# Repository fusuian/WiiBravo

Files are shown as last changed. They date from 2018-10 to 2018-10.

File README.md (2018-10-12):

# WiiBravoアダプタ

ソニー製PlayStation1/2用ゲームコントローラを任天堂製ゲームコントローラWiiリモコンに接続するアダプタです。

DualShock2をクラシックコントローラの代わりとして使えるほか、ナムコ（現バンダイナムコゲームス）製バーチャルコンソールアーケードソフト『超絶倫人ベラボーマン』用に、ボタンを押す強さによって弱中強攻撃（ジャンプ）を行う機能があります。

また、PS用のアーケードコントローラを接続することもできます。
このとき、バーチャルコンソールのファミコンソフトとメガドライブソフトが遊びやすいようにボタン配列を変更できます。

## ハードウェア

WiiBravoアダプタは、マイコンボードと電子部品をブレッドボードに組み付けて作成します。

ブレッドボードの配線図は、 WiiBravo.fzz またはWiiBravo_BreadBoard.pdfをご覧ください。

 - ブレッドボード ハーフサイズ
 - マイコンボード Arduino Pro mini (3.3V版)
 - カーボン抵抗 560Ω x 1
 - カーボン抵抗 1kΩ x 3
 - 赤、黄、青色のLED 各1
 - ジャンパワイヤ 適宜

 - PlayStationコネクタ (マルチタップなどを分解して入手) x 1
 - Wiiリモコンケーブル (ヌンチャクのケーブルを切断) x 1

## ソフトウェア

USBシリアル変換モジュールでPCとArduino Pro Miniを接続して、
Arduino IDEで WiiBravo スケッチを書き込みます。

 - WiiBravo.ino         スケッチ本体
 - BravoButton.h        ベラボースイッチクラス
 - portmacro.h          digitalWrite に相当する、portOn/portOffマクロを定義

以下のソフトウェアは、Bruno Freitas氏によるwii-retropad-adapterをもとに、Arduino 1.8でビルドするための変更を加えています。

https://github.com/bootsector/wii-retropad-adapter

 - WMExtension.h/cpp    Wiiリモコン拡張コントローラ通信クラス
 - WMCrypt.h/cpp        Wiiリモコン拡張コントローラ通信暗号化クラス

### PS2X_libライブラリ

Bill Porter氏による、PlayStationコントローラ読み取りライブラリです。

https://github.com/madsci1016/Arduino-PS2X からダウンロードして、Arduino/libraliesフォルダに展開してください。

### ライセンス

ソフトウェアのライセンスはGPL3となります。詳しくはWiiBravo.inoをご覧ください。

## 使用方法

WiiBravoアダプタに PlayStationコントローラを接続してから、Wiiリモコンを接続します。

DualShock2とアーケードコントローラをつなぎ換える場合は、一度WiiBravoアダプタを外してからコントローラを抜き差ししてください。

### クラシックコントローラモード

PlayStationコントローラとしてDualShock2を接続すると、赤のLEDが1秒間点滅して、クラシックコントローラモードで起動します。

クラシックコントローラモードでは、ボタンは以下のように対応します。

                  DualShock2  : Wii クラシックコントローラ
                  R1 □ △ L1 :  R y x L
                  R2 ✕ ◯ L2 : ZR b a ZL

### ベラボーマンモード

クラシックコントローラモードで、SELECTボタンとL1ボタンを一緒に押すと青のLEDが1秒間点滅して、ベラボーマンモードになります。

ベラボーマンモードでは、△ボタンと✕ボタンが攻撃ボタンになり、□ボタンと◯ボタンがジャンプボタンになります。

各ボタンは、押し込む強さによって三段階の強さの攻撃またはジャンプになります。

(攻撃ボタンはy,x,L、ジャンプボタンはb,a,Rのいずれかを押したことになる)

L1ボタンとR1ボタンは使用しません。

R2ボタンでコイン投入、L2ボタンまたはSTARTボタンでゲームスタートとなります。

ベラボーマンモードでSELECTボタンとR1ボタンを一緒に押すと、クラシックコントローラモードになります。

### アーケードコントローラモード

PlayStationコントローラとしてアーケードコントローラを接続すると、赤のLEDが約1秒間点滅してアーケードコントローラモードで起動します。

作者はHORI製リアルアーケードPSのボタン配置を改造したものを使用していますが、他社製のコントローラでも使えると思います。

アーケードコントローラモードでは、ボタンは以下のように対応します。

       アーケードコントローラ : Wiiクラシックコントローラ
                  L2 □ △ L1 : ZL y x L
                  R2 ✕ ◯ R1 : ZR b a R

### ファミコンモード

また、SELECTボタンとL1ボタンを同時に押すと、黄色のLEDが約1秒間点滅してファミコンモードに移行します。

ファミコンモードでは、ボタンは以下のように対応します。

       アーケードコントローラ : Wiiクラシックコントローラ
                  L2 □ △ L1 : ZL y b a
                  R2 ✕ ◯ R1 : ZR x y a

このとき、上の段の y,b,a は、バーチャルコンソールのメガドライブソフトでは、メガドライブコントローラのA,B,Cボタンとして機能します。

そして下の段の x,y,a は、バーチャルコンソールのファミコンソフトでは、A,B,Aボタンとして機能します。

ファミコンモードでSELECTボタンとR1ボタンを同時に押すと、黄色のボタンが約1秒間点滅してアーケードコントローラモードに戻ります。

# トラブルシューティング

## PlayStationコントローラをつないでも方向キーやボタンが使えない

赤のLEDが長い周期で点滅していた場合、PlayStationコントローラを認識できていません。

このときは、WiiBravoアダプタからPlayStationコントローラを外し、WiiリモコンからWiiBravoアダプタを外し、もう一度接続し直してください。

それでも解決しない場合は、PlayStationコントローラまわりの配線やWiiケーブルを確認してください。

## ホームキーを押すには

Wiiコントローラのホームキーを押すには、SELECTボタンと方向キーの上を同時に押します。

## ベラボーマンモードで、弱中強の押し分けがうまくいかない

ソースコードWiiBravo.inoを修正して、Arduino Pro Miniのプログラムを更新します。

    const byte      low_max =  128;
    const uint16_t  middle_max   =  1000;

low_maxは、0～255までの値をとりますが、値が大きすぎると中や強が出にくくなります。
middle_maxは0～65535までの値をとりますが、low_maxより小さくしてはいけません。また、low_maxに近い値では中が出にくく、値が大きすぎると強が出にくくなります。

ボタンを押したフレームにおける押し下げ圧p1がlow_maxより小さければ弱、次のフレームでの押し下げ圧をp2として、p1*p2がmiddle_maxより小さいとき中、大きいとき強として判定します。

## アーケードコントローラモードで、ボタン配列を変更したい

ソースコードWiiBravo.ino内のac_buttons関数を修正して、Arduino Pro Miniのプログラムを更新します。

    void ac_buttons()
    {
      ab = ps2x.Button(PSB_CIRCLE);
      bb = ps2x.Button(PSB_CROSS);
      xb = ps2x.Button(PSB_TRIANGLE);
      yb = ps2x.Button(PSB_SQUARE);
      lb = ps2x.Button(PSB_L1);
      rb = ps2x.Button(PSB_R1);

      lt = lb*255;
      rt = rb*255;
    }

上記のプログラムでは、左辺であるab, bb, xb, yb, lb, rbはそれぞれWiiクラシックコントローラのa,b,x,y,L,Rボタンに対応します。

右辺のps2x.Buttonのカッコ内のPSB_CIRCLE, PSB_CROSS, PSB_TRIANGLE, PSB_SQUARE, PSB_L1, PSB_R1は、それぞれPlayStationアーケードコントローラの◯,✕,△,□,L1,R1ボタンに対応します。

手持ちのコントローラに合わせてそれぞれの代入式を変更してください。

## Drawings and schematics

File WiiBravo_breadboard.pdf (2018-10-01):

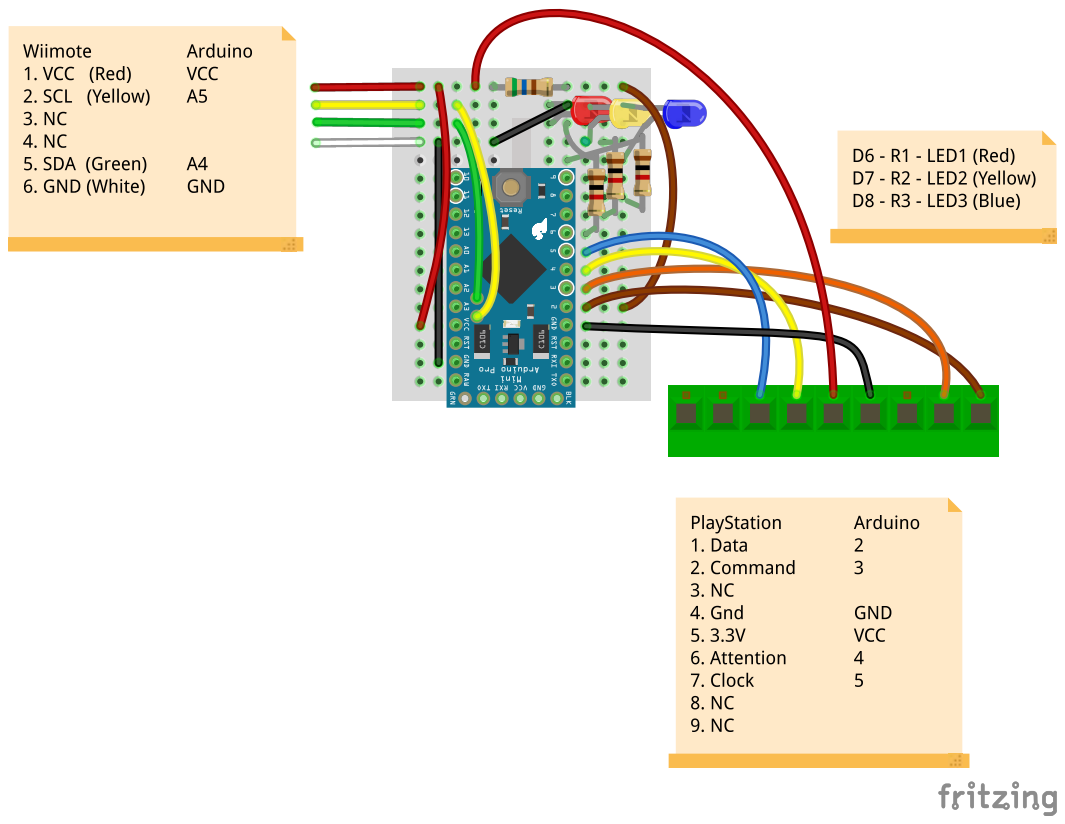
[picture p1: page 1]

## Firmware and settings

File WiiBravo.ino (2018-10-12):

/**
 * WiiBravo - Sony DualShock2 Controller Adapter for Wii (especially designed for Bravoman)
 * Copyright (c) 2018 ASAHI,Michiharu <fusuian@gmail.com>
 *
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
 * You should have received a copy of the GNU General Public License
 * along with WiiBravo.  If not, see <http://www.gnu.org/licenses/>.
 */


#include <PS2X_lib.h>  // v1.6
#include "WMExtension.h"
#include "BravoButton.h"
#include "portmacro.h"

#define ULONG_MAX (4294967295)

// ベラボーマンモードでの、弱中強のしきい値
const byte      low_max =  128;
const uint16_t  middle_max   =  1000;

// DualShock2のアナログスティックのしきい値
const byte threshold = 64;

// 動作モードフラグ

// DualShock2モード
// true: DualShock2が接続されている
// false: PS1初代コントローラまたはアーケードコントローラが接続されている
bool ds2_mode = false;

// ベラボーモード
// select+Rでオン、select+Lでオフ
// ds2_mode が真:
//      true: DualShock2のボタンがそれぞれ、弱中強３段階の攻撃/ジャンプボタンになる。
//      false: クラシックコントローラ配列
// ds2_mode が偽:
//      true: PS1コントローラのボタンをVCのメガドライブ配列(上段)
//            ファミコン配列(下段)に割り当てる
//      false: クラシックコントローラ配列
bool bravo_mode = false;


BravoButton attack_button(low_max, middle_max);
BravoButton jump_button(low_max, middle_max);
BravoButton attack_button2(low_max, middle_max);
BravoButton jump_button2(low_max, middle_max);

// インジケータLEDピン
const byte weak_pin = 6;
const byte middle_pin = 7;
const byte strong_pin = 8;
const byte red_pin = 6;



// PlayStation コントローラ読み取りピン
#define PS2_DAT       2
#define PS2_CMD       3
#define PS2_SEL       4
#define PS2_CLK       5

#define pressures   true
#define rumble      false

PS2X ps2x;

int error = 0;
byte type = 0;
byte vibrate = 0;

// Wiiリモコンへ送る各ボタンのフラグ
byte up, down, left, right;
byte start, select, home;
byte ab, bb, xb, yb;   // A/B/X/Yボタン
byte lb, rb, zlb, zrb; // L/R/ZL/ZRボタン
byte lx, ly, rx, ry;   // アナログスティックL/R
byte lt, rt;           // アナログトリガーL/R

byte clx, cly, crx, cry;  // アナログスティックの中央値

// エラーが発生したら赤LEDをチカチカさせる
void stop_by_error()
{
  while (true) {
    digitalWrite(red_pin, HIGH);
    delay(100);
    digitalWrite(red_pin, LOW);
    delay(900);
  }
}


void setup()
{
  Serial.begin(57600);
  while (Serial == false)
    ;

  pinMode(weak_pin, OUTPUT);
  pinMode(middle_pin, OUTPUT);
  pinMode(strong_pin, OUTPUT);
  portOff(weak_pin);
  portOff(middle_pin);
  portOff(strong_pin);

  // PSコントローラ初期化
  error = ps2x.config_gamepad(PS2_CLK, PS2_CMD, PS2_SEL, PS2_DAT, pressures, rumble);
  Serial.print(F("error = "));
  Serial.println(error);
  if (error == 0){
    Serial.println(F("Found Controller, configured successful"));
  } else if (error == 1) {
    Serial.println(F("No controller found"));
    stop_by_error();
  } else if (error == 2) {
    Serial.println(F("Controller found but not accepting commands"));
  } else if (error == 3) {
    Serial.println(F("Controller refusing to enter Pressures mode"));
  }

  // DualShock2であればベラボーマンモード、PS1コントローラであればデジタルモード
  type = ps2x.readType();
  Serial.print(F("type = "));
  Serial.println(type);
  switch(type) {
  case 0:
    Serial.println(F("Digital Controller found"));
    break;
  case 1:
    Serial.println(F("DualShock Controller found"));
    ds2_mode = true;
    break;
  default:
    Serial.println(F("Unknown Controller found"));
    stop_by_error();
    break;
  }

  if (ds2_mode) {
    while (ps2x.enablePressures() == false) {
      delay(16);
    }
  }
  blinkStart(pinx(), 60);

  // Wiiリモコン初期化
  WMExtension::init();
  Serial.println(F("WM init"));
  clx = WMExtension::get_calibration_byte(2);
  cly = WMExtension::get_calibration_byte(5);
  crx = WMExtension::get_calibration_byte(8);
  cry = WMExtension::get_calibration_byte(11);
}

// 1/60秒単位のウェイトをより正確に
void delay16()
{
  static unsigned long m = 0;
  unsigned long n = micros();

  if (n >= m) {
    n -= m;
  } else {
    n += ULONG_MAX - m;
  }
  delayMicroseconds(10000 - n);
  delayMicroseconds(6666);
  m = micros();
}

byte blink_count;
byte blink_pin;
byte blink_mode;
const byte blink_frames = 5;


void bravo_buttons()
{
  lt = rt = 0;
  yb = xb = lb = 0;
  bb = ab = rb = 0;
  byte vsquare = ps2x.Analog(PSAB_SQUARE);
  jump_button2.update(vsquare, bb, ab, rb);
  byte vcircle = ps2x.Analog(PSAB_CIRCLE);
  jump_button.update(vcircle, bb, ab, rb);
  byte vcross = ps2x.Analog(PSAB_CROSS);
  attack_button.update(vcross, yb, xb, lb);
  byte vtriangle = ps2x.Analog(PSAB_TRIANGLE);
  attack_button2.update(vtriangle, yb, xb, lb);
}


void digital_keys()
{
  lx = left? 0 : (right? 255 : clx);
  ly = down? 0: (up? 255: cly);
  rx = left? 0 : (right? 255 : crx);
  ry = down? 0: (up? 255: cry);
}


void analog_sticks()
{
  // クラコンのアナログスティックのビット幅の変換はライブラリに任せる
  lx =  ps2x.Analog(PSS_LX);
  if (abs(lx) < threshold) { lx = 0; }
  ly =  255 - ps2x.Analog(PSS_LY); // y軸を反転
  if (abs(ly) < threshold) { ly = 0; }

  rx =  ps2x.Analog(PSS_RX);
  if (abs(rx) < threshold) { rx = 0; }
  ry = 255 - ps2x.Analog(PSS_RY); // y軸を反転
  if (abs(ry) < threshold) { ry = 0; }
}


void classic_buttons()
{
  xb = ps2x.Button(PSB_TRIANGLE);
  ab = ps2x.Button(PSB_CIRCLE);
  yb = ps2x.Button(PSB_SQUARE);
  bb = ps2x.Button(PSB_CROSS);

  lb = ps2x.Button(PSB_L1);
  rb = ps2x.Button(PSB_R1);

  // L1/R1のアナログ値をL/Rトリガー値としてセット。
  // (VCAのアサルト以外に、トリガー値使ってるゲームあるの？)
  lt =  ps2x.Analog(PSAB_L1);
  rt =  ps2x.Analog(PSAB_R1);
}


void ac_buttons()
{
  ab = ps2x.Button(PSB_CIRCLE);
  bb = ps2x.Button(PSB_CROSS);
  xb = ps2x.Button(PSB_TRIANGLE);
  yb = ps2x.Button(PSB_SQUARE);
  lb = ps2x.Button(PSB_L1);
  rb = ps2x.Button(PSB_R1);

  lt = lb*255;
  rt = rb*255;
}


void fc_buttons()
{
  lt = rt = 0;
  yb = xb = lb = 0;
  bb = ab = rb = 0;

  // 上段: メガドラ用   y b a : # A L1
  yb |= ps2x.Button(PSB_SQUARE);
  bb |= ps2x.Button(PSB_TRIANGLE);
  ab |= ps2x.Button(PSB_L1);

  // 下段: ファミコン用 x y a : x o R1
  xb |= ps2x.Button(PSB_CROSS);
  yb |= ps2x.Button(PSB_CIRCLE);
  ab |= ps2x.Button(PSB_R1);
}


void blinkStart(byte pin, int count)
{
  blink_pin = pin;
  blink_count = count;
  blink_mode = HIGH;
}


void  blinkUpdate()
{
  if (blink_count > 0) {
      if (--blink_count % blink_frames == 0) {
        blink_mode = !blink_mode;
        if (blink_mode) {
          portOn(blink_pin);
        } else {
          portOff(blink_pin);
        }
      }
  }
  if (blink_count <= 0) {
    portOff(blink_pin);
  }
}


byte pinx()
{
  if (ds2_mode) {
    if (bravo_mode) {
      return strong_pin;
    } else {
      return weak_pin;
    }
  } else {
    if (bravo_mode) {
      return middle_pin;
    } else {
      return weak_pin;
    }
  }
}


void loop()
{
  blinkUpdate();

  ps2x.read_gamepad(false, vibrate);

  up    = ps2x.Button(PSB_PAD_UP);
  down  = ps2x.Button(PSB_PAD_DOWN);
  left  = ps2x.Button(PSB_PAD_LEFT);
  right = ps2x.Button(PSB_PAD_RIGHT);

  start  = ps2x.Button(PSB_START);
  select = ps2x.Button(PSB_SELECT);
  home = up && select;

  zlb = ps2x.Button(PSB_L2);
  zrb = ps2x.Button(PSB_R2);

  if (ds2_mode) {
    analog_sticks();
    if (bravo_mode) {
      bravo_buttons();
    } else {
      classic_buttons();
    }
  } else {
    digital_keys();
    if (bravo_mode) {
      fc_buttons();
    } else {
      ac_buttons();
    }
  }

  // モードが変わっても切り替えに使うボタンはL1/R1
  if (select & ps2x.Button(PSB_L1)) {
    bravo_mode = true;
    blinkStart(pinx(), 60);
  }
  if (select & ps2x.Button(PSB_R1)) {
    bravo_mode = false;
    blinkStart(pinx(), 60);
  }

  if (yb | bb) {
    portOn(weak_pin);
  } else {
    portOff(weak_pin);
  }
  if (xb | ab) {
    portOn(middle_pin);
  } else {
    portOff(middle_pin);
  }
  if (lb | rb) {
    portOn(strong_pin);
  } else {
    portOff(strong_pin);
  }

  WMExtension::set_button_data(left, right, up, down,
    ab, bb, xb, yb,
    lb, rb,
    select, start, home,
    lx, ly, rx, ry,
    zlb, zrb, lt, rt);

  delay16();
}

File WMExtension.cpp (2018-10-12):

/*
* Wii RetroPad Adapter - Nintendo Wiimote adapter for retro-controllers!
* Copyright (c) 2018 ASAHI,Michiharu <fusuian@gmail.com>
* Based on code by Copyright (c) 2011 Bruno Freitas - bruno@brunofreitas.com
*
* Wiimote Extension class based on the arduino-wiimote library (c) by
* Peter Brinkmann: https://gitorious.org/randomstuff/arduino-wiimote
*
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
* You should have received a copy of the GNU General Public License
* along with this program.  If not, see <http://www.gnu.org/licenses/>.
 */

#include <Arduino.h>
#include <Wire.h>
#include "WMExtension.h"
#include "WMCrypt.h"

/* Classic Controller ID */
const byte WMExtension::id[6] = { 0x00, 0x00, 0xa4, 0x20, 0x01, 0x01 };

/*
 *  Classic Controller Calibration Data.
 * Last two bytes (checksum) will be calculated by the init() function
  */
byte WMExtension::calibration_data[16] = { 0xFC, 0x04, 0x7E, 0xFC, 0x04,
		0x7E, 0xFC, 0x04, 0x7E,	0xFC, 0x04, 0x7E, 0x00, 0x00, 0x00, 0x00 };

/* Address requested by the I2C Master Device (i.e., the Wiimote) */
volatile byte WMExtension::address = 0;

/* Tells whether encryption was setup (enabled) or not */
volatile byte WMExtension::crypt_setup_done = 0;

/* Classic Controller 256 data registers */
byte WMExtension::registers[0x100];

/*
 * Callback function pointer that will be called after the Wiimote has requested
 * buttons status (state == 0x00 on handle_request function).
 *
 * First buttons status requested by the Wiimote will be always zeroed, which
 * don't represent a problem.
 *
 * User should provide the callback function which should then call
 * WMExtension::set_button_data function that updates the buttons_data array.
 *
 * The updated array will be provided to the Wiimote when it requests buttons
 * status.
 *
 * This pointer is set when user calls WMExtension::set_button_data_callback
 * which will usually happen during program setup, before calling
 * WMExtension::init function.
 */
WMExtension::CBackPtr WMExtension::cbPtr = NULL;

/* Sets the buttons state update callback function */
void WMExtension::set_button_data_callback(CBackPtr cb) {
	WMExtension::cbPtr = cb;
}

/* Returns 1 of the 16 possible bytes from the calibration data array */
byte WMExtension::get_calibration_byte(int b) {
	if(b >= 0 && b <= 15)
		return WMExtension::calibration_data[b];
	else
		return 0;
}

/*
 * Setup Wiimote <-> Extension I2C communication encryption, if requested by
 * the application (game/homebrew).
 */
void WMExtension::setup_encryption() {
	WMCrypt::wiimote_gen_key(WMExtension::registers + 0x40);

	WMExtension::crypt_setup_done = 1;
}

/*
 * Send 8 bytes data via Wire.write().
 * Supports Wiimote encryption, if enabled.
  */
void WMExtension::send_data(uint8_t* data, uint8_t addr) {
	static uint8_t buffer[21];
	int i, lim;

	lim = 0xFF - addr + 1;

	if(lim >= 21) {
		lim = 21;
	}

	if (WMExtension::crypt_setup_done) {
		for (i = 0; i < lim; i++) {
			buffer[i] = (data[i] - WMCrypt::wm_ft[(addr + i) % 8]) ^ WMCrypt::wm_sb[(addr + i) % 8];
		}

		Wire.write(buffer, lim);
	} else {
		Wire.write(data, lim);
	}
}

/* I2C slave handler for data received from the Wiimote */
void WMExtension::receive_bytes(int count) {
	byte crypt_keys_received = 0;
	byte old_crypt_key_received = 0;

	if (count == 1) {

		WMExtension::address = Wire.read();

		return;

	} else if (count > 1) {

		byte addr = Wire.read();

		for (int i = 1; i < count; i++) {
			byte d = Wire.read();

			// Wii is trying to disable encryption...
			if(addr == 0xF0 && (d == 0x55 || d == 0xAA)) {
				WMExtension::crypt_setup_done = 0;
			}

			// Wii is probably trying to setup old encryption mode
			if(addr == 0x40 && d == 0x00) {
				old_crypt_key_received = 1;
			}

			if (WMExtension::crypt_setup_done) {
				// Decrypt
				WMExtension::registers[addr] = (d ^ WMCrypt::wm_sb[addr % 8]) + WMCrypt::wm_ft[addr
						% 8];
			} else {
				WMExtension::registers[addr] = d;
			}

			// Check if last crypt key setup byte was received...
			if (addr == 0x4F) {
				crypt_keys_received = 1;
			}

			addr++;
		}

	}

	// Setup encryption if requested by the Wii
	if (crypt_keys_received || old_crypt_key_received) {

		if(old_crypt_key_received)
			memset(WMExtension::registers + 0x40, 0x00, 16);

		WMExtension::setup_encryption();
	}
}

/* I2C slave handler for data request from the Wiimote */
void WMExtension::handle_request() {

	WMExtension::send_data(WMExtension::registers + WMExtension::address, WMExtension::address);

	if(WMExtension::address == 0x00) {
		if(WMExtension::cbPtr) {
			WMExtension::cbPtr();
		}
	}
}

/*
 * Takes joystick, and button values and encodes them
 * into a buffer.
 *
 * Classic Controller
 *
 * Buffer encoding details:
 * http://wiibrew.org/wiki/Wiimote/Extension_Controllers/Classic_Controller
 */
void WMExtension::set_button_data(int bdl, int bdr, int bdu, int bdd,
		int ba, int bb, int bx, int by, int blt, int brt, int bminus, int bplus,
		int bhome, byte lx, byte ly, byte rx, byte ry, int bzl, int bzr, int lt, int rt) {

	byte _tmp1, _tmp2;

	_tmp1 = ((bdr ? 1 : 0) << 7) | ((bdd ? 1 : 0) << 6) | ((blt ? 1 : 0)
			<< 5) | ((bminus ? 1 : 0) << 4) | ((bplus ? 1 : 0) << 2)
			| ((brt ? 1 : 0) << 1) | ((bhome ? 1 : 0) << 3);

	_tmp2 = ((bb ? 1 : 0) << 6) | ((by ? 1 : 0) << 5) | ((ba ? 1 : 0)
			<< 4) | ((bx ? 1 : 0) << 3) | ((bdl ? 1 : 0) << 1) | (bdu ? 1
			: 0) | ((bzl ? 1 : 0) << 7) | ((bzr ? 1 : 0) << 2);

	// registers[0xFE] == 0x03: Read mode encoding used by the NES Classic Edition
	if(WMExtension::registers[0xFE] == 0x03) {
		WMExtension::registers[0] = lx;
		WMExtension::registers[1] = rx;
		WMExtension::registers[2] = ly;
		WMExtension::registers[3] = ry;
		WMExtension::registers[4] = lt;
		WMExtension::registers[5] = rt;
		WMExtension::registers[6] = ~_tmp1;
		WMExtension::registers[7] = ~_tmp2;
	} else {
		lx = lx >> 2;
		ly = ly >> 2;
		rx = rx >> 3;
		ry = ry >> 3;
		lt = lt >> 3;
		rt = rt >> 3;

		WMExtension::registers[0] = ((rx & 0x18) << 3) | (lx & 0x3F);
		WMExtension::registers[1] = ((rx & 0x06) << 5) | (ly & 0x3F);
		WMExtension::registers[2] = ((rx & 0x01) << 7) | ((lt & 0x18) << 2) | (ry & 0x1F);
		WMExtension::registers[3] = ((lt & 0x07) << 5) | (rt & 0x1F);
		WMExtension::registers[4] = ~_tmp1;
		WMExtension::registers[5] = ~_tmp2;
		WMExtension::registers[6] = 0;
		WMExtension::registers[7] = 0;
	}
}
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

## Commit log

2018-06-10 接続ピンを変更して、DualShock2のアナログボタン入力をチェック
2018-06-10 Wiiリモコンへの出力クラスを追加(from Wii Retropad Adapter)
2018-06-10 Arduinoのバージョンアップに対応
2018-06-10 サンプルのコメント、フォーマットを変更
2018-06-10 WMExtensionを使って、DualShock2からの入力をクラシックコントローラーのデジタル出力に変換
2018-06-13 ps2xとWMExtensionの初期化順を変更
2018-06-14 シリアルの速度、インデントの調整、メッセージ出力の追加
2018-06-14 ベラボースイッチの実装（大が出しにくい）
2018-06-14 DualShock2を確実にアナログボタンモードで初期化する
2018-06-14 xボタンが押されたときにアナログ値を表示
2018-06-14 2フレームの合計で弱中強ボタンを決定
2018-06-14 コメント行を削除
2018-06-14 DualShock2を初期化するときLEDを点滅
2018-06-23 ピン番号と通信速度の設定変更
2018-06-23 ボタンアナログ値を二乗して、強弱の値を強調。中強のスレッショルド値を変更。変数定義を移動。
2018-06-24 ベラボーキーを□攻撃と×ジャンプに変更
2018-06-24 強攻撃のスレッショルドを調整
2018-06-24 L/Rボタンの配置を変更
2018-06-24 シリアルで弱中強を表示（コメントアウト済み）
2018-06-26 △○ボタンはデジタルボタンとする
2018-06-26 アナログスティックを変換
2018-06-26 ベラボースイッチ処理をBravoButtonクラスにまとめる
2018-06-28 文字列をFマクロに変更
2018-06-28 1/60秒単位のループをより正確に
2018-06-28 アナログスティックの入力値を修正
2018-06-28 シリアル出力を抑制
2018-06-28 コメントを修正
2018-09-29 コメントを削除
2018-09-29 delay16()の関数化
2018-09-29 デジタルスティック対応
2018-09-29 アタックの強さに応じてLEDを点灯
2018-09-29 BravoButtonからbuttonメンバを削除
2018-09-29 コントローラがつながっていない、未対応コントローラであるなどの場合、赤ランプを点滅させる
2018-09-29 グローバル変数mをdelay16のスタティック変数に変更
2018-09-29 updateで一度変数をクリア
2018-09-29 ボタン4つすべてを攻撃またはジャンプに割り当てる
2018-09-29 弱中強のしきい値を変更
2018-09-30 むだなintをbyteに変更
2018-09-30 micro()に合わせてintをunsigned longに変更
2018-09-30 改造アケコンに対応するMY_CUSTOM_CONTROLLERを追加
2018-09-30 不要コードを削除
2018-09-30 コメント追加とスタイルの小変更
2018-10-01 BravoButton::updateで、ボタン変数をクリアしない
2018-10-01 弱中強のLED点灯を、BravoButton::update()からloop()に移動
2018-10-01 update()の引数vsquareを、byteからintに戻す（vsquare*=psquareがbyteだとオーバーフローして、強パンチが出ないエンバグの原因）
2018-10-01 ボタン圧値のデバッグ表示を変更（したうえでコメントアウト）
2018-10-01 デジタルモードで、左アナログスティックにもレバーの動きを反映する（Wiiホームメニュー等でカーソルを動かせる）
2018-10-01 デジタルモードでVCファミコンやVCメガドラを遊びやすくするfc_modeを追加
2018-10-01 fc_modeの切替時に、LEDを点滅させる
2018-10-01 コメントとしきい値を調整
2018-10-01 配線図を追加
    [WiiBravo.fzz]
2018-10-01 リネーム
2018-10-01 ソースの崩れを修正
2018-10-01 GPLv3ライセンスを追加
2018-10-01 コメント削除
2018-10-01 isPinを更新
2018-10-05 fc_modeを削除してds2_modeを追加、DualShock2のクラコンモードを追加。 コントローラのキーやボタンを変換するルーチンをdigital_keys(), analog_sticks(), classic_buttons(), bravo_buttons(), fc_buttons()に分割。
2018-10-05 アナログスティックのしきい値を設定
2018-10-05 LEDの点滅をblinkStart(), blinkUpdate()に分割。
2018-10-05 メンバ変数vsquareを削除、間違いが入らないようvsquare*psquareの値を変数valueに納める。
2018-10-08 L/RアナログトリガーにL1/R1のアナログ値を入れる
2018-10-08 モード切り替えボタンは、モードが変わってもL1/R1に固定する
2018-10-08 MY_CUSTOM_CONTROLLERシンボルを削除
2018-10-08 モードのコメントからボタン配列を削除
2018-10-08 fc_buttons()を見やすく変更
2018-10-08 アーケードコントローラのボタン変換関数ac_buttonsを追加
2018-10-08 変数thresh_middle, thresh_highをlow_max, middle_maxに変更
2018-10-08 Serial.printをまとめる
2018-10-08 アナログスティックのしきい値を変更
2018-10-08 README.mdを追加
2018-10-12 copyright表記を修正
2018-10-12 Copyright表記を変更
2018-10-12 段落を調整

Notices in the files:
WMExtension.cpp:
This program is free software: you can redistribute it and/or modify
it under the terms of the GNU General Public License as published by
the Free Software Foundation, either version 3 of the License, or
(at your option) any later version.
